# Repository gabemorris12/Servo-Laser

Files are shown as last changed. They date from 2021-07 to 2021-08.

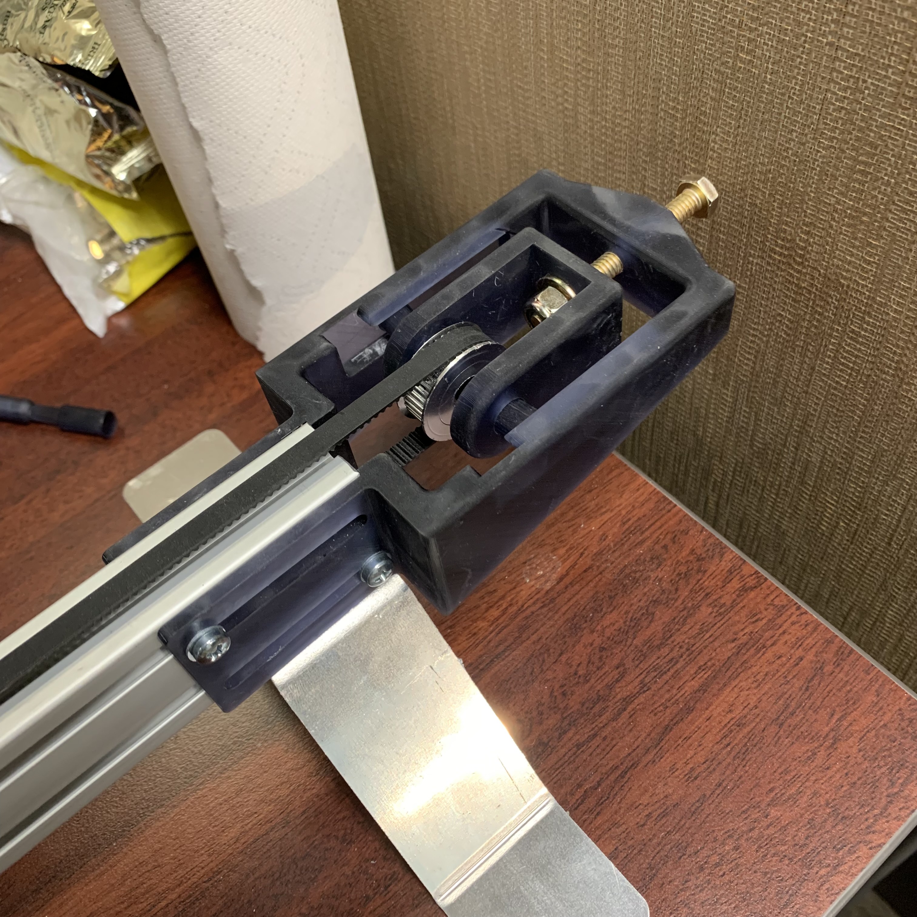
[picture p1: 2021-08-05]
Photos/Tensioner.jpg

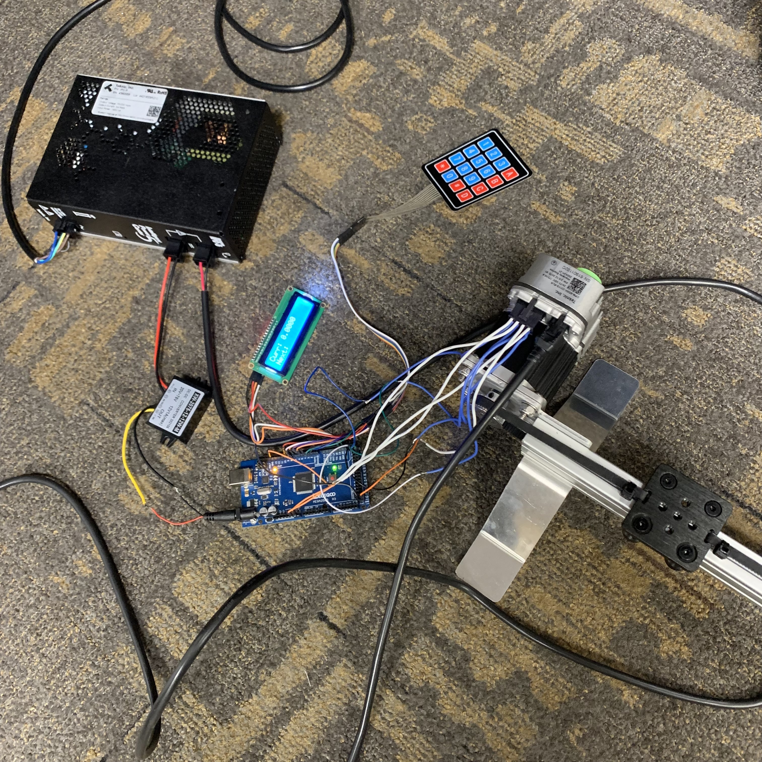
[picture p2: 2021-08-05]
Photos/Power Supply.jpg

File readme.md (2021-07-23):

# Purpose

***
In this project, a ClearPath servo from Teknic is programmed via Arduino Mega. The system takes in a distance input in
inches, then moves a laser to that distance (tolerance is within a 1/16th of an inch). The system is belt driven. Here
are the required components used for this project:

* [Arduino Mega](https://www.amazon.com/gp/product/B01EWNUUUA/ref=ppx_yo_dt_b_asin_title_o09_s00?ie=UTF8&psc=1)
* [Keypad](https://www.amazon.com/outstanding-Adhesive-Membrane-Keyboard-Prototyping/dp/B08JYNM8D9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)
* [Liquid Crystal I2C](https://www.amazon.com/gp/product/B0711WLVP9/ref=ppx_yo_dt_b_asin_title_o00_s00?ie=UTF8&psc=1)
* ClearPath Servo (SDSK model). Accessories can be
  found [here](https://www.teknic.com/clearpath-accessories-guide/accessories-guide-sd-dc/).
    * Power Supply (IPC-5)
    * Power Cables (IPC to ClearPath)
    * Controller Cable (8-pin molex mini)
    * Micro USB for ClearPath Setup
* DC to Dc Converter. This is used to step down the 75V power supply to 12V. One can be
  found [here](https://www.amazon.com/SMAKN-Converter-20V-75V-Module-96W-Waterproof/dp/B0711R5ZDR).
* Arduino Shield (optional). One was
  found [here](https://www.amazon.com/Electronics-Salon-Prototype-Terminal-Arduino-MEGA-2560/dp/B00UT13YXA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)
* Belt Components:
    * Tensioner (see parts folder)
    * Lase Mount (see parts folder)
    * [Aluminum Extrusion](https://www.grainger.com/product/80-20-Framing-Extrusion-16U249)
    * [GT2 Timing Pulley](https://www.amazon.com/gp/product/B077P8PQHK/ref=ppx_yo_dt_b_asin_title_o02_s00?ie=UTF8&psc=1)
    * [GT2 Timing Belt](https://www.amazon.com/gp/product/B07MF6TDHF/ref=ppx_yo_dt_b_asin_title_o03_s00?ie=UTF8&psc=1)
    * [Laser](https://www.amazon.com/gp/product/B07CGG8LDX/ref=ppx_yo_dt_b_asin_title_o08_s00?ie=UTF8&psc=1)
    * [Plate Kit](https://www.amazon.com/gp/product/B08B65GKRD/ref=ppx_yo_dt_b_asin_title_o09_s01?ie=UTF8&psc=1) (for
      mounting laser)

# Environment

***
Here are the libraries that are not standard:

* [LiquidCrystal_I2C](https://github.com/johnrickman/LiquidCrystal_I2C)
* Keypad ([Download Here](https://playground.arduino.cc/uploads/Code/keypad/index.zip))
* [ClearPathStepGen](https://github.com/Teknic-ClearPath/ClearPath-Arduino-Step-And-Direction/tree/master/Arduino%20Uno/ClearPathStepGen)

*Libraries are installed in "C:\Users\username\OneDrive\Documents\Arduino\libraries"*

If there are libraries missing, then troubleshoot at runtime.

# Additional References

***

## NYC CNC

* Good examples for using the ClearPath classes and move method are found [here](https://youtu.be/ZRURwDFvdAs?t=225).
* See more examples on using the ClearPath package under the example folder in the ClearPathStepGen package.

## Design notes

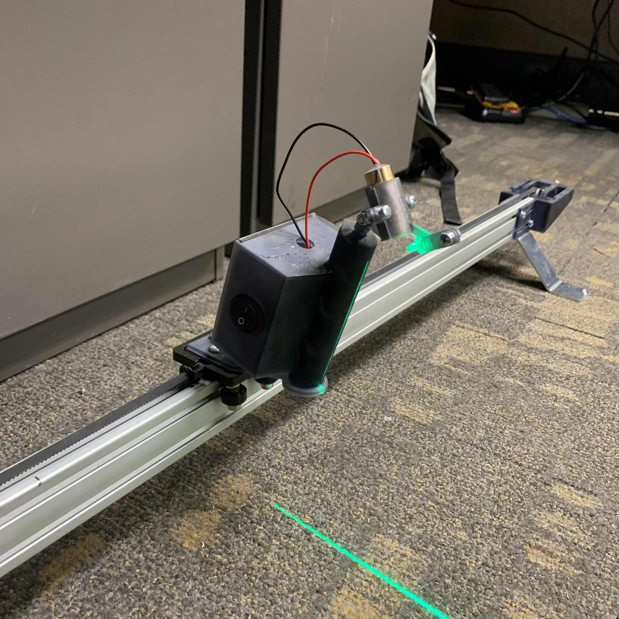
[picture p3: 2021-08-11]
Photos/Laser Mount.jpg

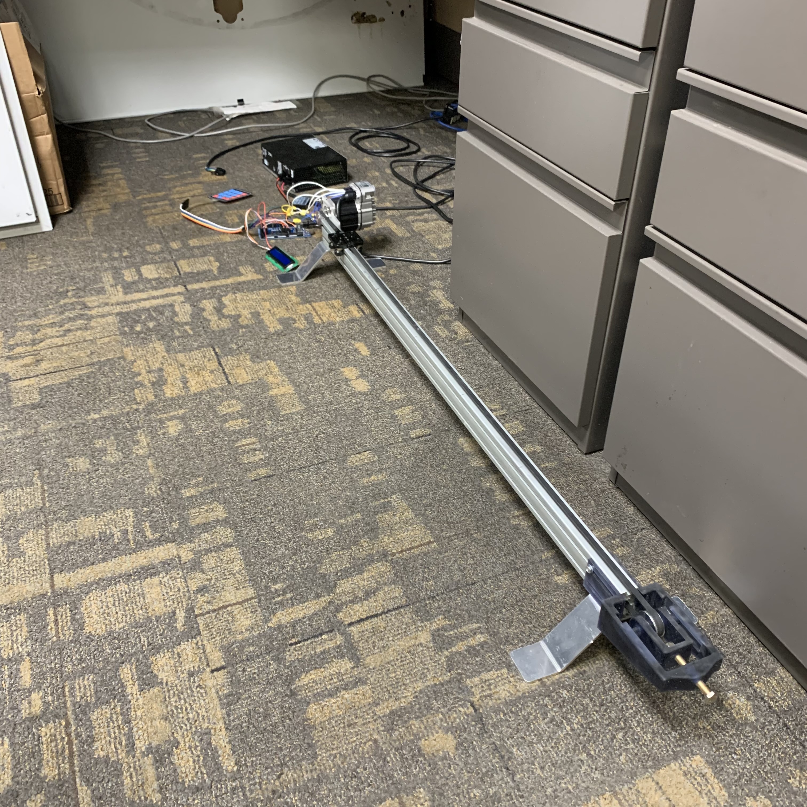
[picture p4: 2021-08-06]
Photos/First Model.jpg

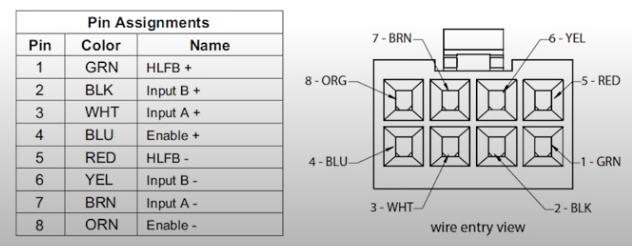
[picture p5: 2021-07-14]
Clear Path General I-O.PNG

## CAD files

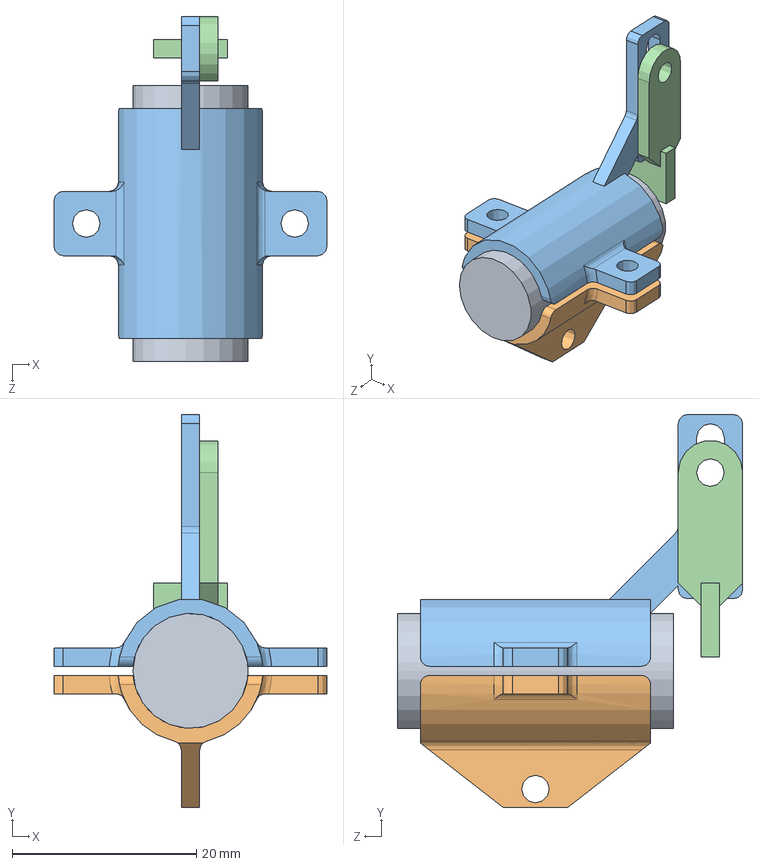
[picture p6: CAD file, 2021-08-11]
SolidWorks/Laser Mount/Laser Couple Mount.SLDASM
29.6 x 42.7 x 37.5 mm
Laser
Laser Couple Bottom
Laser Couple Top
Blocker

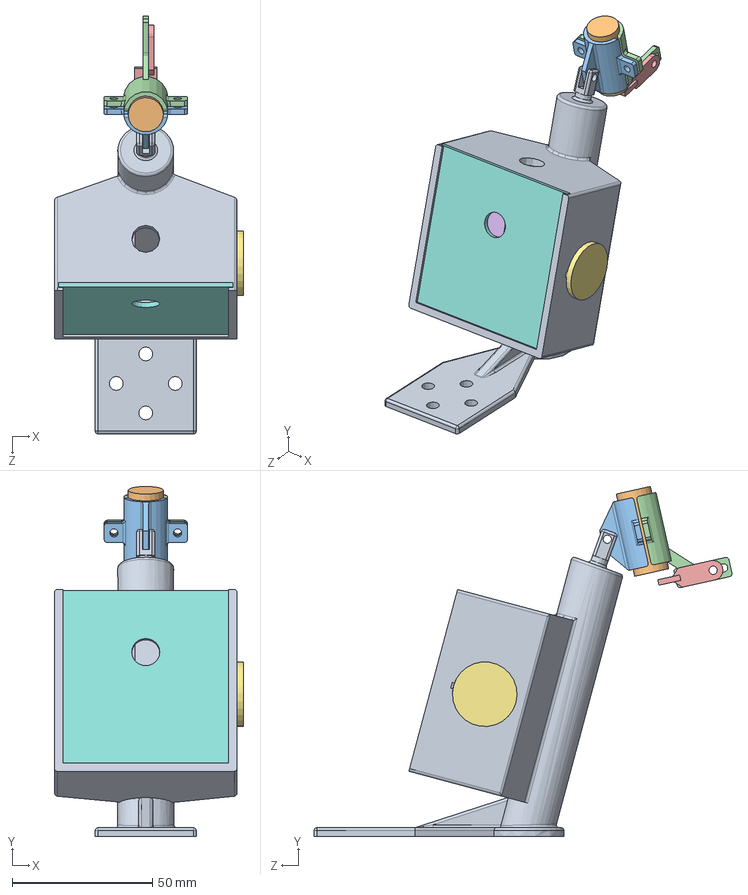
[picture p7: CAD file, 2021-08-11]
SolidWorks/Laser Mount/Laser Mount Assembly.SLDASM
67.3 x 124.6 x 148.8 mm
Laser Mount
Laser
Laser Couple Bottom
Laser Couple Top
Blocker
Battery
Switch
Slider

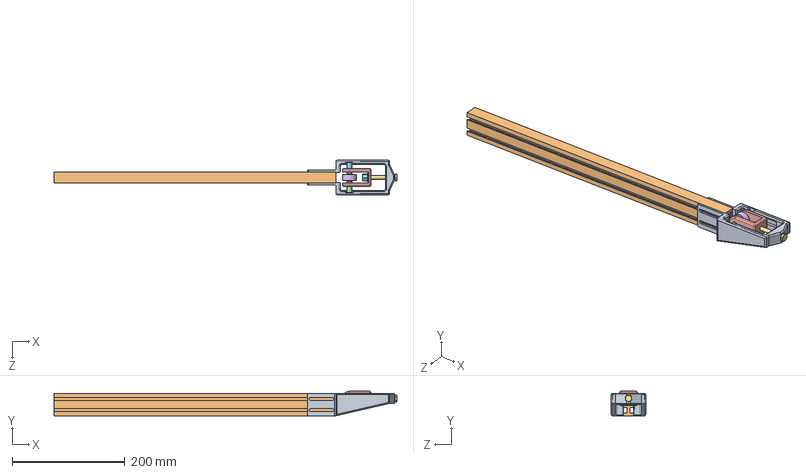
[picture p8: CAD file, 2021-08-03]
SolidWorks/Tensioner Assembly/Tensioner_Assembly.SLDASM
608.2 x 43.6 x 61.3 mm
Tensioner Outer
Rail
Center Female
Center Male
Tensioner Inner
Servo_Wheel
HHCS 25
LOCK NUTS
WASHERS

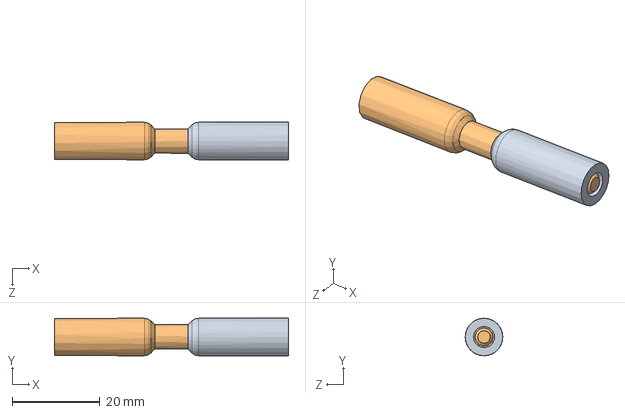
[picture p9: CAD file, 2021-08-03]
SolidWorks/Tensioner Assembly/Assem1.SLDASM
53.3 x 8.57 x 8.57 mm
Center Male
Center Female

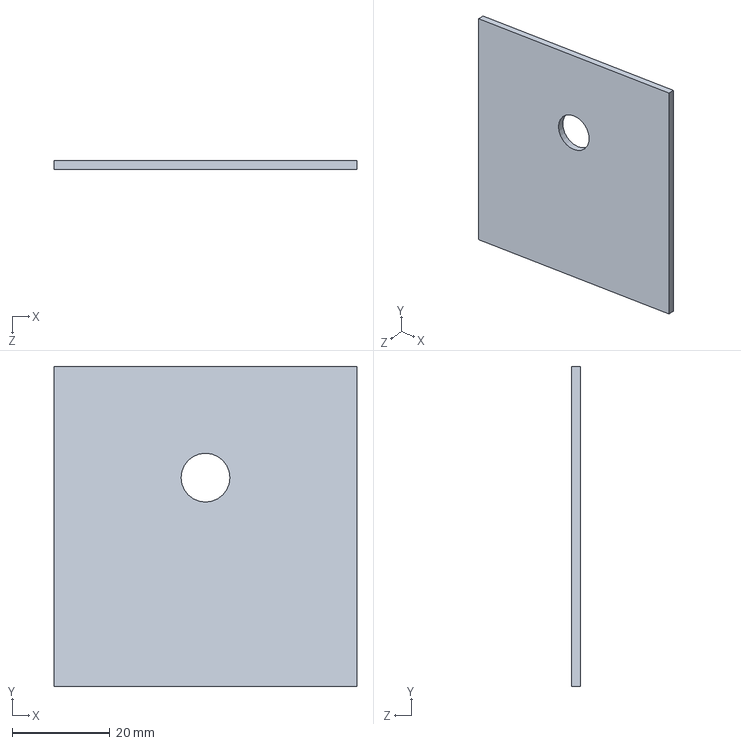
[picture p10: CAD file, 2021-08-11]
SolidWorks/Laser Mount/Slider.SLDPRT
62.0 x 65.5 x 1.80 mm

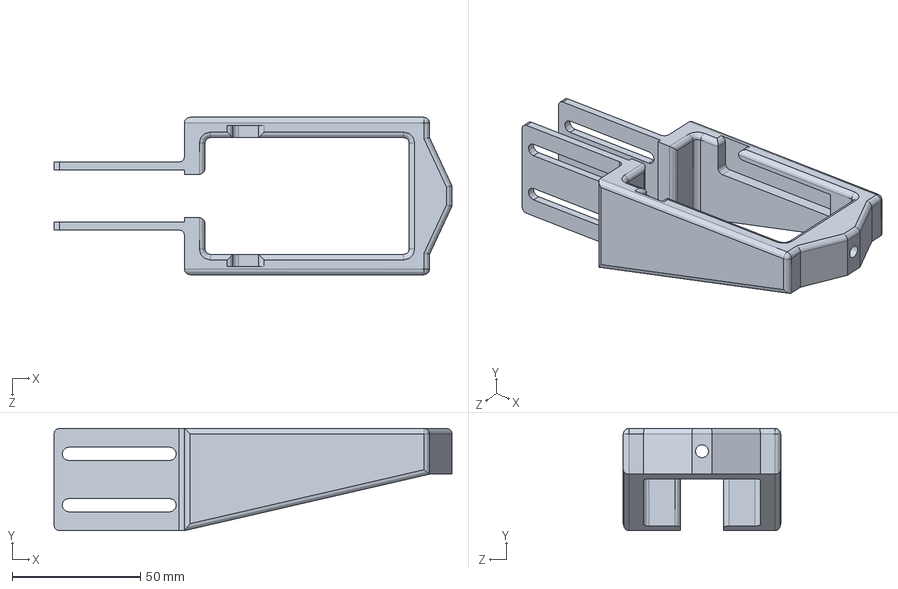
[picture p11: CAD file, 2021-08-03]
SolidWorks/Tensioner Assembly/Tensioner Outer.SLDPRT
154.9 x 39.8 x 61.3 mm

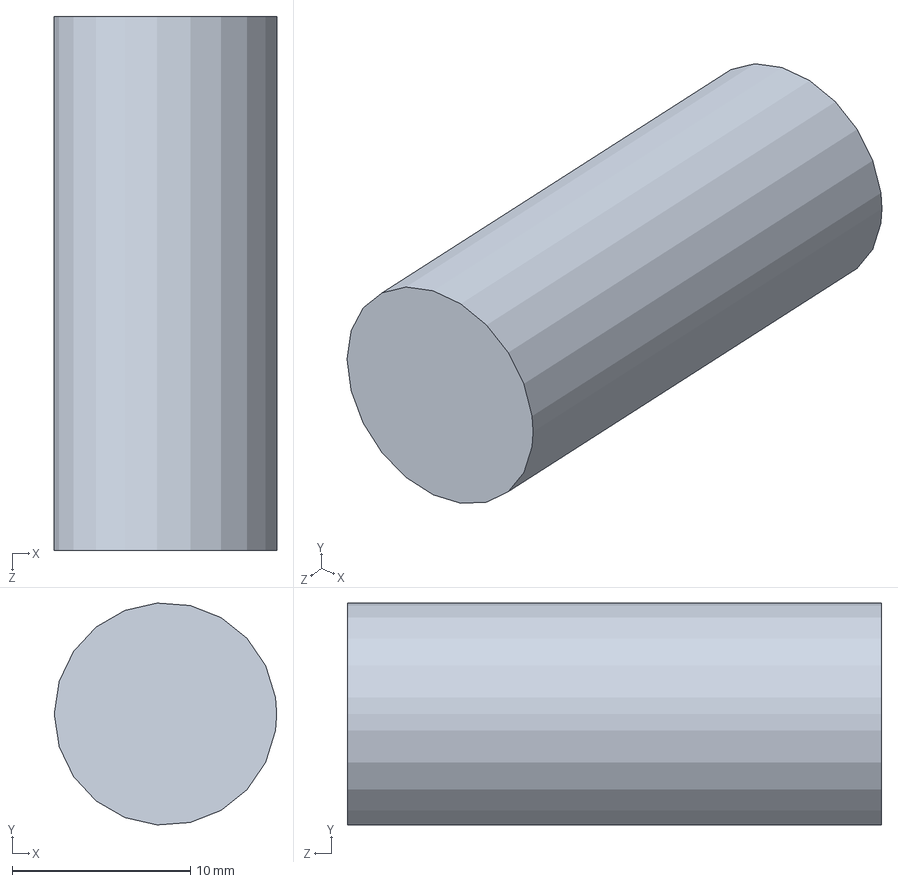
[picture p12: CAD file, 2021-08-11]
SolidWorks/Laser Mount/Laser.SLDPRT
12.5 x 12.5 x 30.0 mm

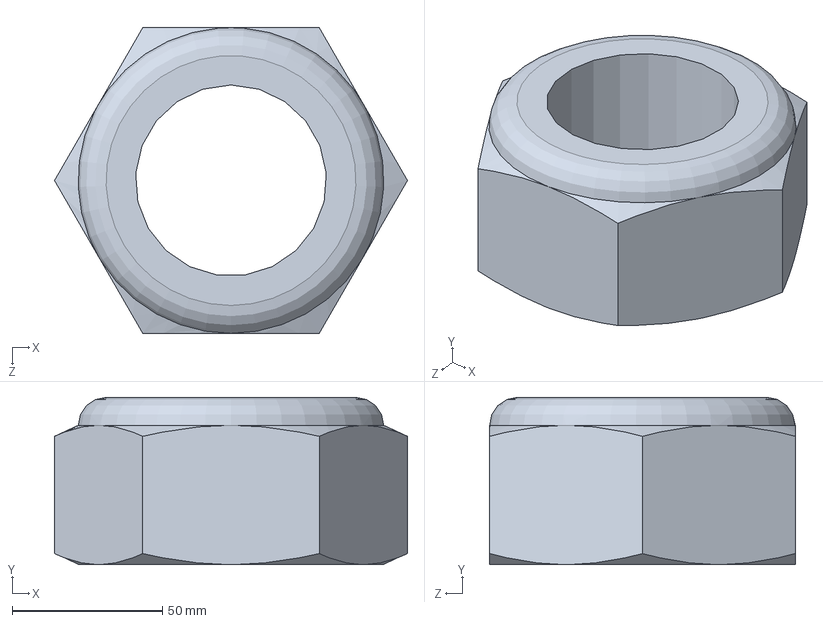
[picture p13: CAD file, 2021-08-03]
SolidWorks/Tensioner Assembly/LOCK NUTS.SLDPRT
117.3 x 55.6 x 101.6 mm

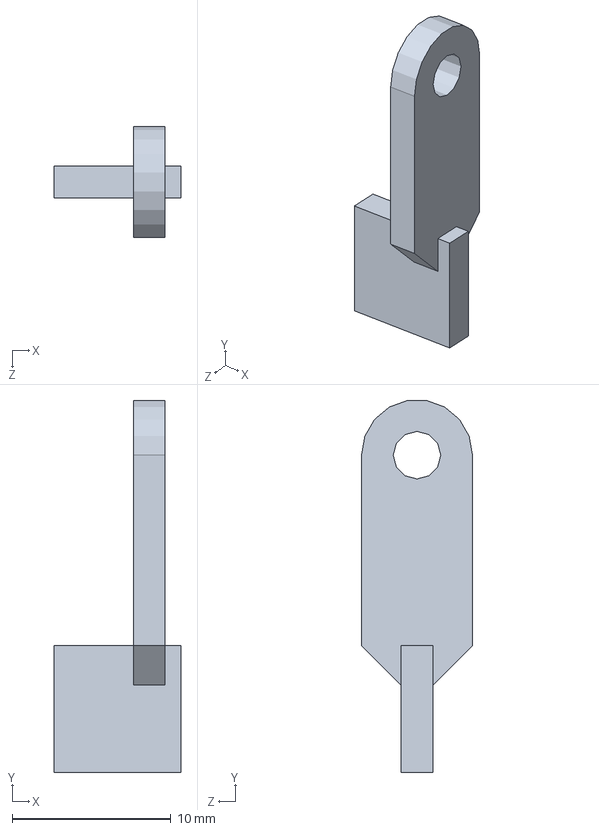
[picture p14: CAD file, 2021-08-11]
SolidWorks/Laser Mount/Blocker.SLDPRT
8.00 x 23.4 x 7.00 mm

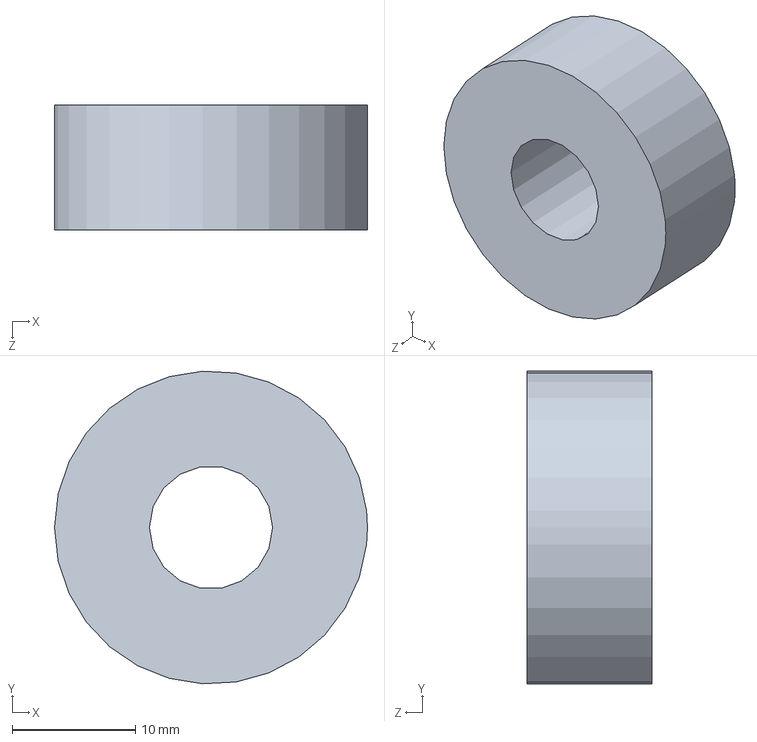
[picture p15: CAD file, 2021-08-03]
SolidWorks/Tensioner Assembly/Servo_Wheel.SLDPRT
25.4 x 25.4 x 10.2 mm

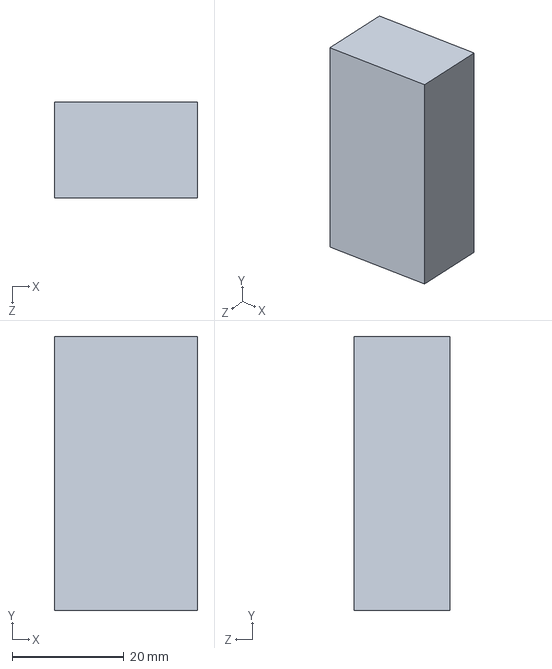
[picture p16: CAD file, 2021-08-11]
SolidWorks/Laser Mount/Battery.SLDPRT
25.6 x 49.0 x 17.1 mm

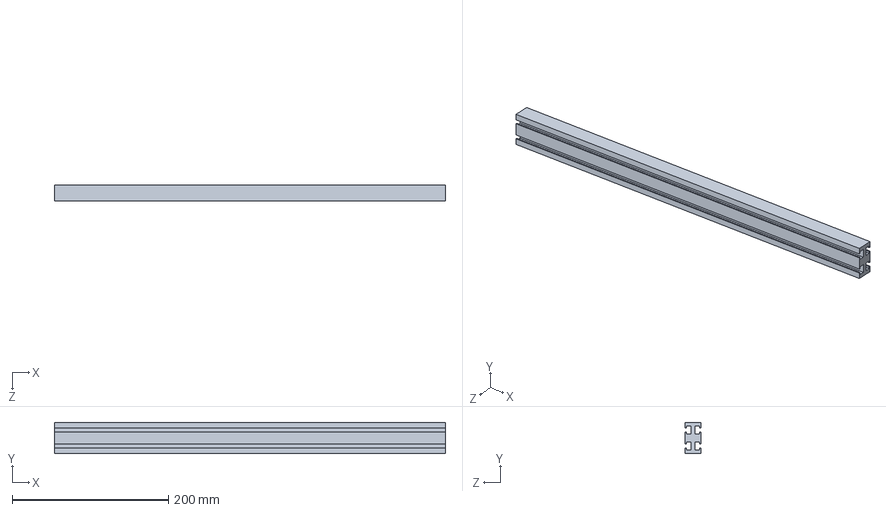
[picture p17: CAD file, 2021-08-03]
SolidWorks/Tensioner Assembly/Rail.SLDPRT
500.0 x 39.8 x 19.9 mm

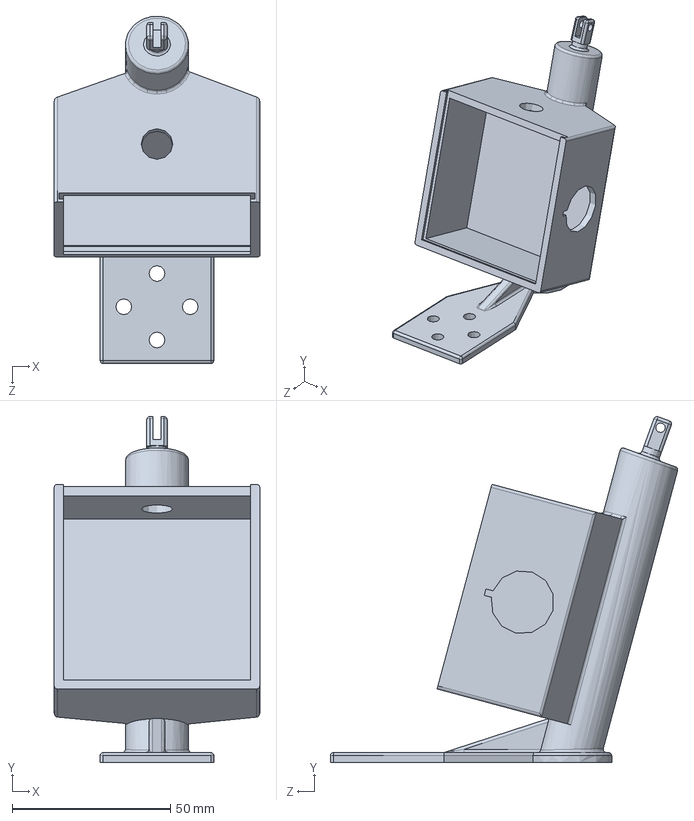
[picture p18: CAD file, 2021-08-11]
SolidWorks/Laser Mount/Laser Mount.SLDPRT
65.0 x 109.4 x 109.8 mm

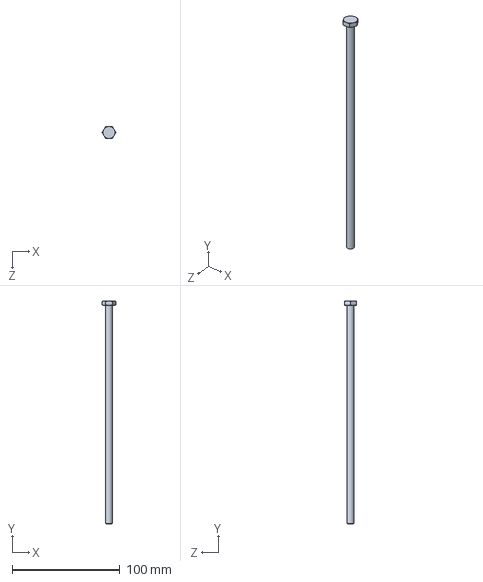
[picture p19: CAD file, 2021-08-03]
SolidWorks/Tensioner Assembly/HHCS 25.SLDPRT
12.8 x 207.2 x 11.1 mm

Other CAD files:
SolidWorks/Laser Mount/Laser Couple Top.SLDPRT
SolidWorks/Tensioner Assembly/Center Female.SLDPRT
SolidWorks/Laser Mount/Switch.SLDPRT
SolidWorks/Tensioner Assembly/Tensioner Inner.SLDPRT
SolidWorks/Laser Mount/Laser Couple Bottom.SLDPRT
SolidWorks/Tensioner Assembly/Center Male.SLDPRT
SolidWorks/Tensioner Assembly/WASHERS.SLDPRT

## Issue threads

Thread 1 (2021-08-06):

Make Power Supply Box

gabemorris12, 2021-08-06:
Make a box to hold the power supply, arduino, keypad, and LCD display. The box should also house the motor with the shaft coming out of it. I think all this should be laser cut because there will need to be a cutout for the LCD as well.

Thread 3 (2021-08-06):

Improve the Pin

gabemorris12, 2021-08-06:
The pin that holds the pulley on the other side needs to be made of metal. The stress is too much for that plastic to handle. The designs are on GitHub, and the only thing that I would consider changing is the width that allows the wheel to slide. I have it set to the width of the wheel, but it needs to be the depth of the bearing (8mm).

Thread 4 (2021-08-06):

Make a New Wheel

gabemorris12, 2021-08-06:
The bearing in that same pulley is not sitting perfectly. This is causing a wobble. That needs to be redone. The wheel needs to be reordered. We already have plenty of needle bearings.

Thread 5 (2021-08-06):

Make a Final Model

gabemorris12, 2021-08-06:
A final model needs to be made with the previous issues fixed and also with a longer rail. Figure out the appropriate length of new railing for the jig table and a way to attach the extrusions.
More details:
* The parameters for the equation that drives this process may need to be adjusted. Because of the linear relationship between the number of revolutions and the circumference of the wheel, the error will increase with distance. The error on the model is too small to see because the rail is only 28 inches, but I can imagine that there will be a visible difference once a 240 inch rail gets used. Details on how to adjust these values are commented in the code.
* With the increased length of the final model, the tensioner length may also need to be changed. The increased length of the belt will decrease its strain; therefore, to account for this loss in strain, the belt will need to be stretched more. The current tensioner allows for a change in length of 1 inch. Keep in mind that the bolt length will also need to vary with the length of the tensioner.

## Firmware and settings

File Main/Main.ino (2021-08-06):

// The only things that may require adjustment are the max_position and the diameter. 
// View their corresponding comments.
#include <Keypad.h>

#include <Wire.h>
#include <LiquidCrystal_I2C.h>

#include <ClearPathMotorSD.h>
#include <ClearPathStepGen.h>

# define M_PI 3.14159265358979323846

ClearPathMotorSD X;
ClearPathStepGen machine(&X);

const byte ROWS = 4;
const byte COLS = 4;

char hexa_keys[ROWS][COLS] = {
  {'1', '2', '3', '\0'},
  {'4', '5', '6', 'B'},
  {'7', '8', '9', 'C'},
  {'.', '0', '\0', 'D'}
};

byte row_pins[ROWS] = {6, 7, 8, 9};
byte col_pins[COLS] = {2, 3, 4, 5};

Keypad custom_keypad = Keypad(makeKeymap(hexa_keys), col_pins, row_pins, COLS, ROWS);

LiquidCrystal_I2C lcd(0x27, 16, 2);

char input[12];
int index = 0;

float current_position = 0.00;
float next_position;
int max_position = 28;  // The maximum position in inches. Adjust this value depending on the length of the rail.

float diameter = 1.0015;  // Diameter of the wheel in inches. Adjust this value to change the distance.
// Governing equation: pulses = resolution(distance)/(pi*diameter) and the resolution is a constant 800.
// If the actual measurement is greater than the laser distance, then decrease the diameter to send more pulses.
// If the actual measurement is smaller than the laser distance, then increase the diameter to send fewer pulses.


void setup() {
  // put your setup code here, to run once:
  Serial.begin(9600);

  lcd.init();
  lcd.backlight();

  X.attach(22, 23, 24, 25);  // Direction/A is pin 22, Step/B is pin 23, Enable is pin 24, HLFB is pin 25

  X.setMaxVel(20000);  // Value between 2 and 100,000 steps/sec
  X.setMaxAccel(50000);  // Value between 4000 and 2,000,000 steps/sec^2

  X.enable();  // Homimg will automatically occur at this call. Be sure to account for its moving.
  lcd.setCursor(0, 0);
  lcd.print("Homing");  
  // HLFB needs to be set to ASG-Position. X.readHLFB() returns 0 when the motor is in motion.
  while (!X.readHLFB()) {
    Serial.println("Homing");
  }

  delay(100);

  machine.Start();
}

void loop() {
  // put your main code here, to run repeatedly:
  lcd.setCursor(0, 0);
  lcd.print("Curr: ");
  lcd.print(current_position, 4);
  lcd.setCursor(0, 1);
  lcd.print("Next: ");
  lcd.print(input);

  char key = custom_keypad.getKey();

  if (key && key != 'D') {
    lcd.clear();
    input[index] = key;
    index++;
  }
  else if (key && key == 'D') {
    next_position = atof(input);
    if (next_position > max_position) {
      lcd.clear();
      lcd.print("Out of Range");
      delay(2000);
    }
    else {
      X.move(get_count(current_position) - get_count(next_position));  // To reverse the direction, swap the current_position and next_position.
      while (!X.commandDone()) {
        Serial.println("Moving");
      }
      Serial.println("Done Moving");
      current_position = next_position;
    }
    reset();
  }
  
  if (key == 'C' || index == 11) {
    reset();
  }

  // B is the homing key.
  if (key == 'B') {
    reset();
    X.disable();
    delay(100);
    X.enable();
    lcd.setCursor(0, 0);
    lcd.print("Homing");
    while (!X.readHLFB()) {
      Serial.println("Homing");
    }
    current_position = 0.0;

  delay(100);
    
  }
}

void clear_input() {
  for (int i = 0; i < sizeof input; i++) {
    input[i] = '\0';
  }
}

void reset() {
  clear_input();
  lcd.clear();
  index = 0;
}

float get_count(float distance) {
  return 800*distance/(M_PI*diameter);
}

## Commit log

2021-07-23 added belt components to readme
2021-08-03 added tensioner assembly
    [Assem1.SLDASM, Center Female.SLDPRT, Center Male.SLDPRT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]
2021-08-05 added homing
2021-08-05 made homing process better
2021-08-11 added mount pic
2021-08-11 added laser mount
    [Battery.SLDPRT, Blocker.SLDPRT, Laser Couple Bottom.SLDPRT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]
